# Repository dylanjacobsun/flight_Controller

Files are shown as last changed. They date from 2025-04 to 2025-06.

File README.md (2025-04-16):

# Objective
Purpose of this project is to develop an autonomous flying wing that will fly waypoint
missions. I am designing and building everything myself including electrical schematics,
PCB layout, component assembly, and system testing. The flight controller will be running 
on FreeRTOS and will be programmed in C.

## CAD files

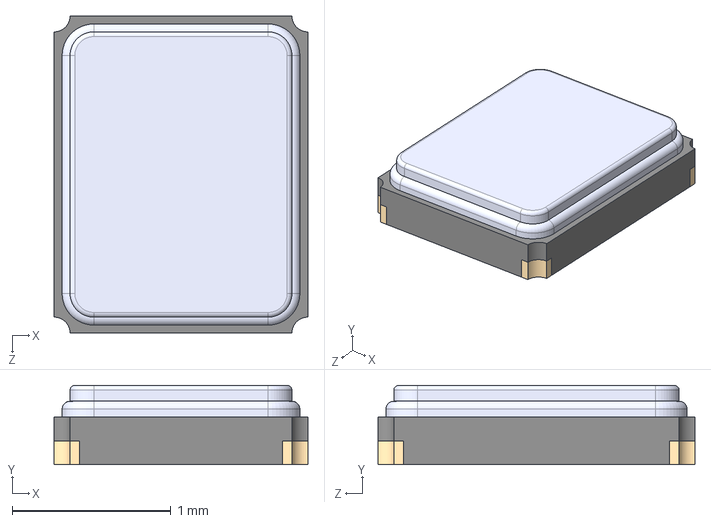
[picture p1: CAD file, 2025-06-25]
Components/Tranny_OSC.step
1.60 x 0.5 x 2.00 mm

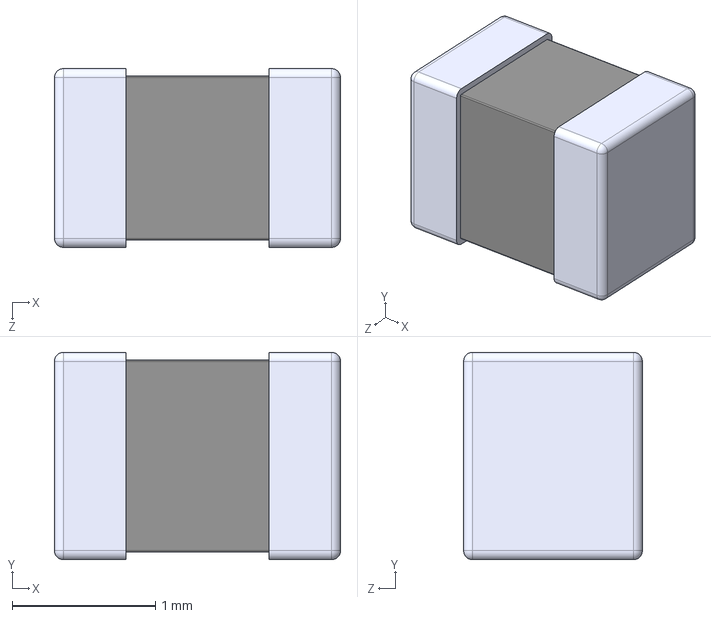
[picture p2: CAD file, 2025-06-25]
Components/15uH_Inductor.step
2.00 x 1.45 x 1.25 mm

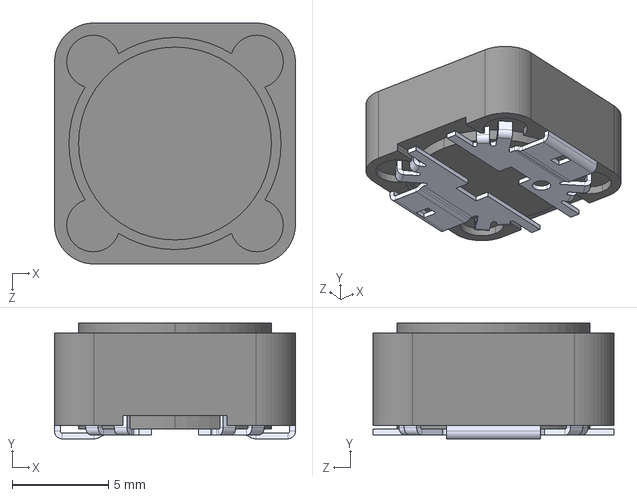
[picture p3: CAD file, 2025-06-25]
Components/4.7uH_7.18A.step
12.5 x 6.00 x 12.5 mm

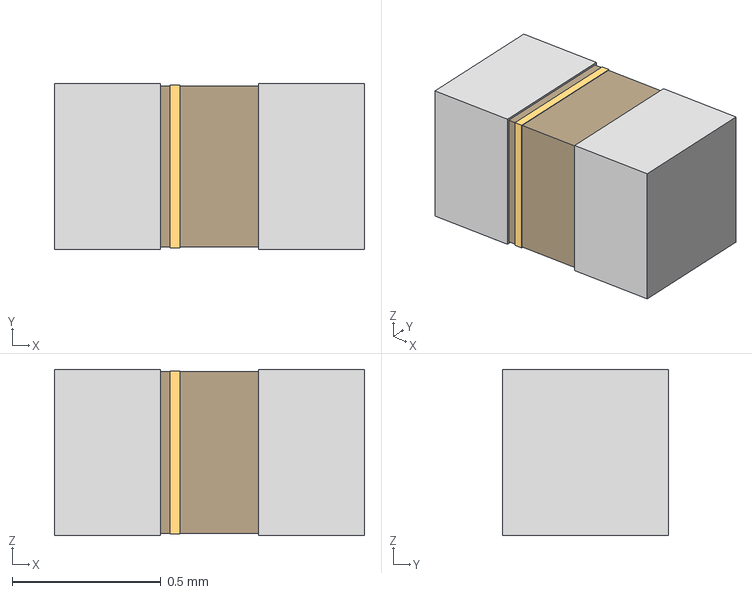
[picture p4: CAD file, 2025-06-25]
Components/10nH_Inductor.step
1.04 x 0.558 x 0.559 mm

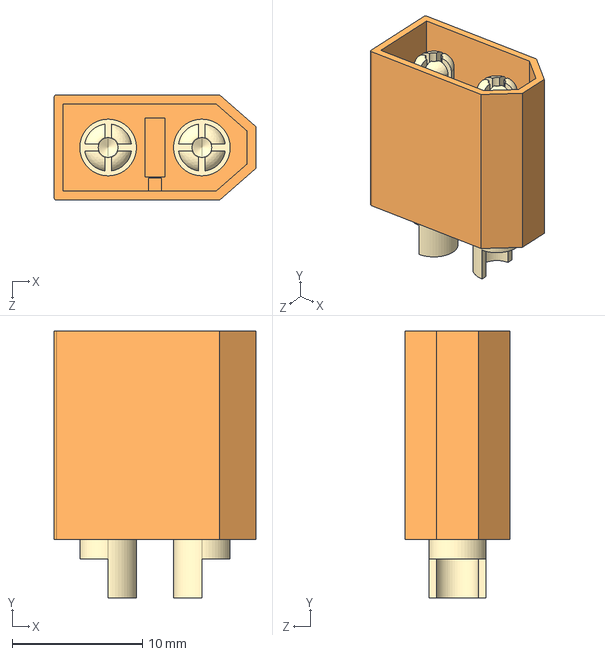
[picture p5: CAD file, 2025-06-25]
Components/XT60-M.step
15.5 x 20.5 x 8.10 mm

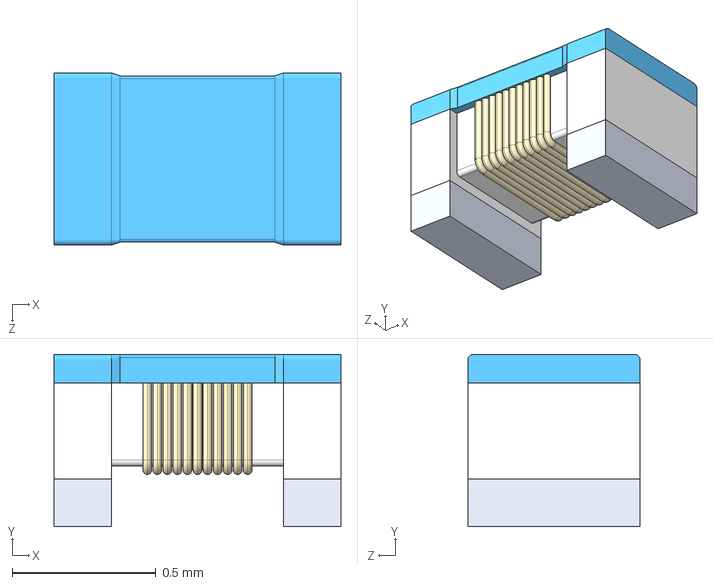
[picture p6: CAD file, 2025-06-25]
Components/3.0nH_Inductor.step
1.00 x 0.6 x 0.6 mm

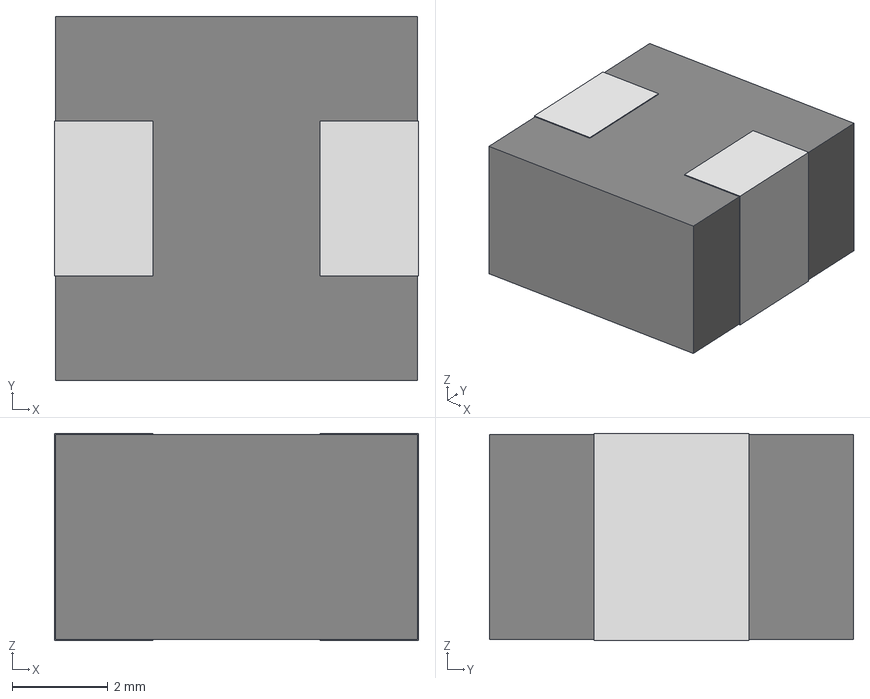
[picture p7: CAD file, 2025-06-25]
Components/3.3uH_3.94A.step
7.62 x 7.62 x 4.34 mm

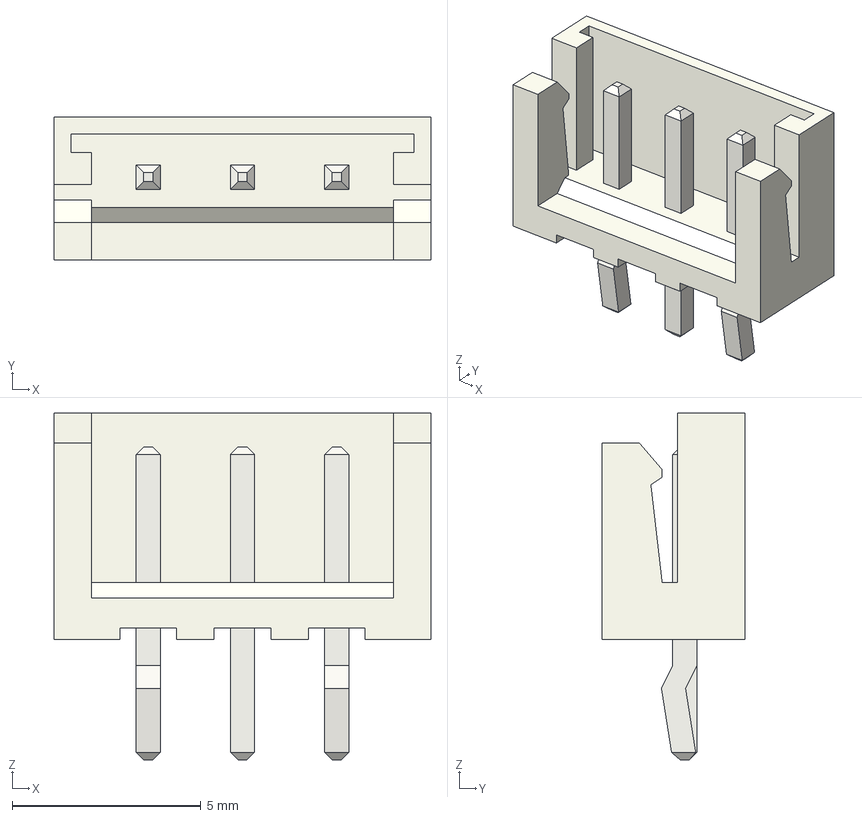
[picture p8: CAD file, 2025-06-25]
Components/JST_EH_B3B-EH-A_1x03_P2.50mm_Vertical.step
10.0 x 3.80 x 9.20 mm

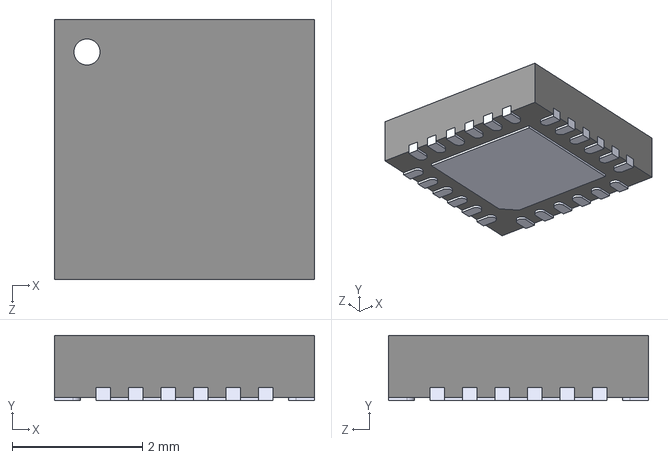
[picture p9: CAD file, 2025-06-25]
Components/Tranny.step
4.00 x 1.00 x 4.00 mm

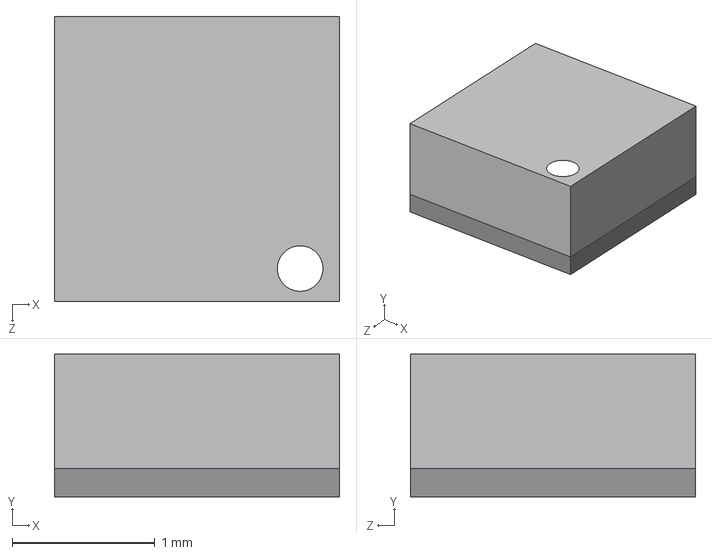
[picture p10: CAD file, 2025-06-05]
Components/Magnetometer.STEP
2.00 x 1.00 x 2.00 mm

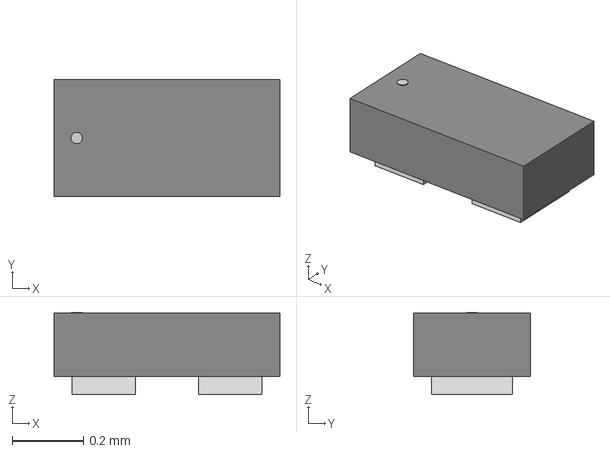
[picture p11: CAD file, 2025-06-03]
Components/ESD_6V.step
0.636 x 0.33 x 0.231 mm

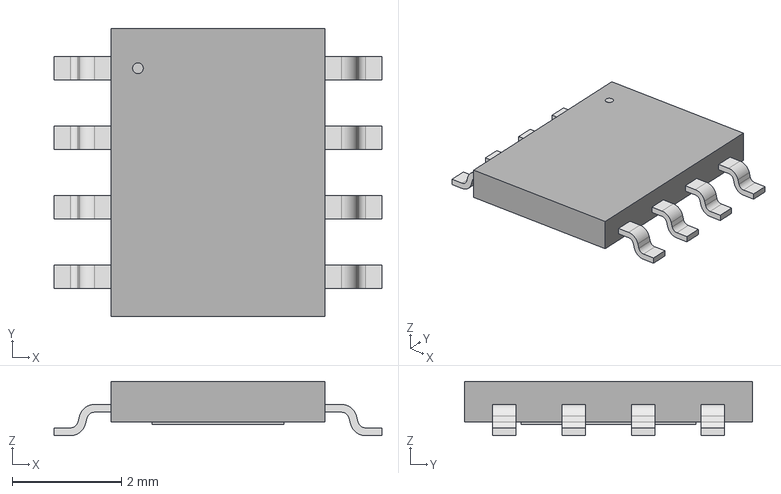
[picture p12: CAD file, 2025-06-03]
Components/3.3V-LDO (1).step
5.99 x 5.26 x 0.993 mm

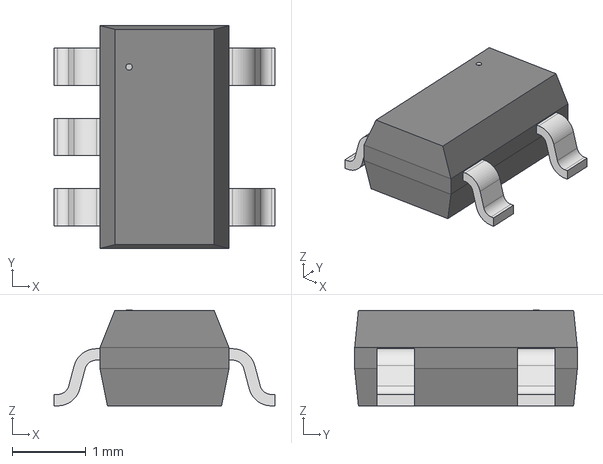
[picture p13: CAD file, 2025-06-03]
Components/Current-Limiter-500mA (1).step
3.00 x 3.02 x 1.30 mm

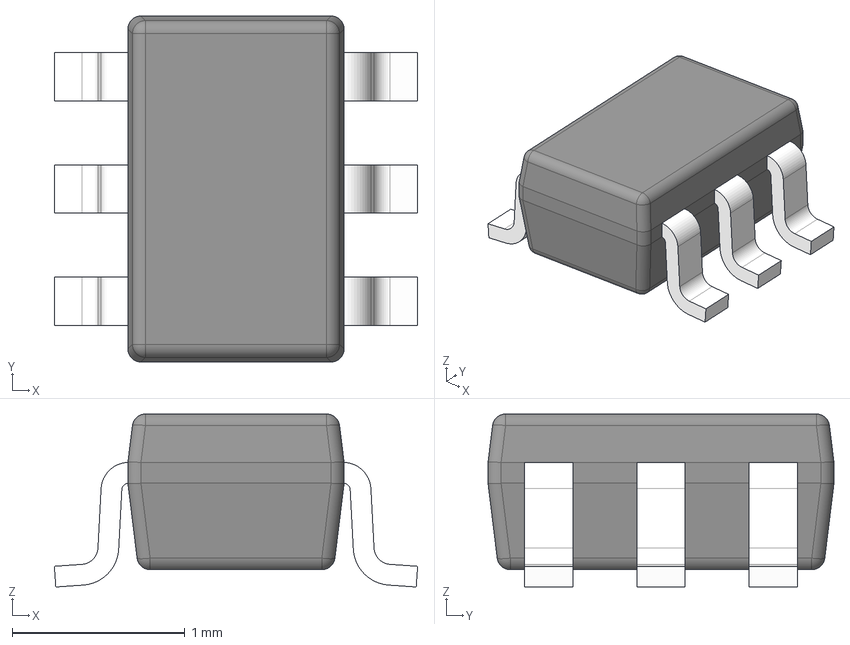
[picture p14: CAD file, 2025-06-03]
Components/Ideal_diode (1).stp
2.10 x 2.00 x 1.00 mm
BODY-SOT
LEAD-SOT x 6
PIN1-ID

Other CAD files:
Components/10nF_Cap_0603.step
Components/2.2uF_CAP_0603.step
Components/01uF_Cap_0603.step
Components/33.2Resistor.step
Components/0.22Cap.step
Components/01uF_CAP.step
Components/10kResistor.step
Components/10uF_cap.step
Components/22Uf_CAP.step
Components/3.3Buck.step
Components/3_3_Inductor.step
Components/Crystal.step
Components/DPS368XTSA1.step
Components/ICM-42670-P.step
Components/STM32F446VET6.step
Components/TESEO-LIV3F.step
Components/TPS22944 (1).stp
Components/U.FL-R-SMT_10_.step
Components/usbc.stp

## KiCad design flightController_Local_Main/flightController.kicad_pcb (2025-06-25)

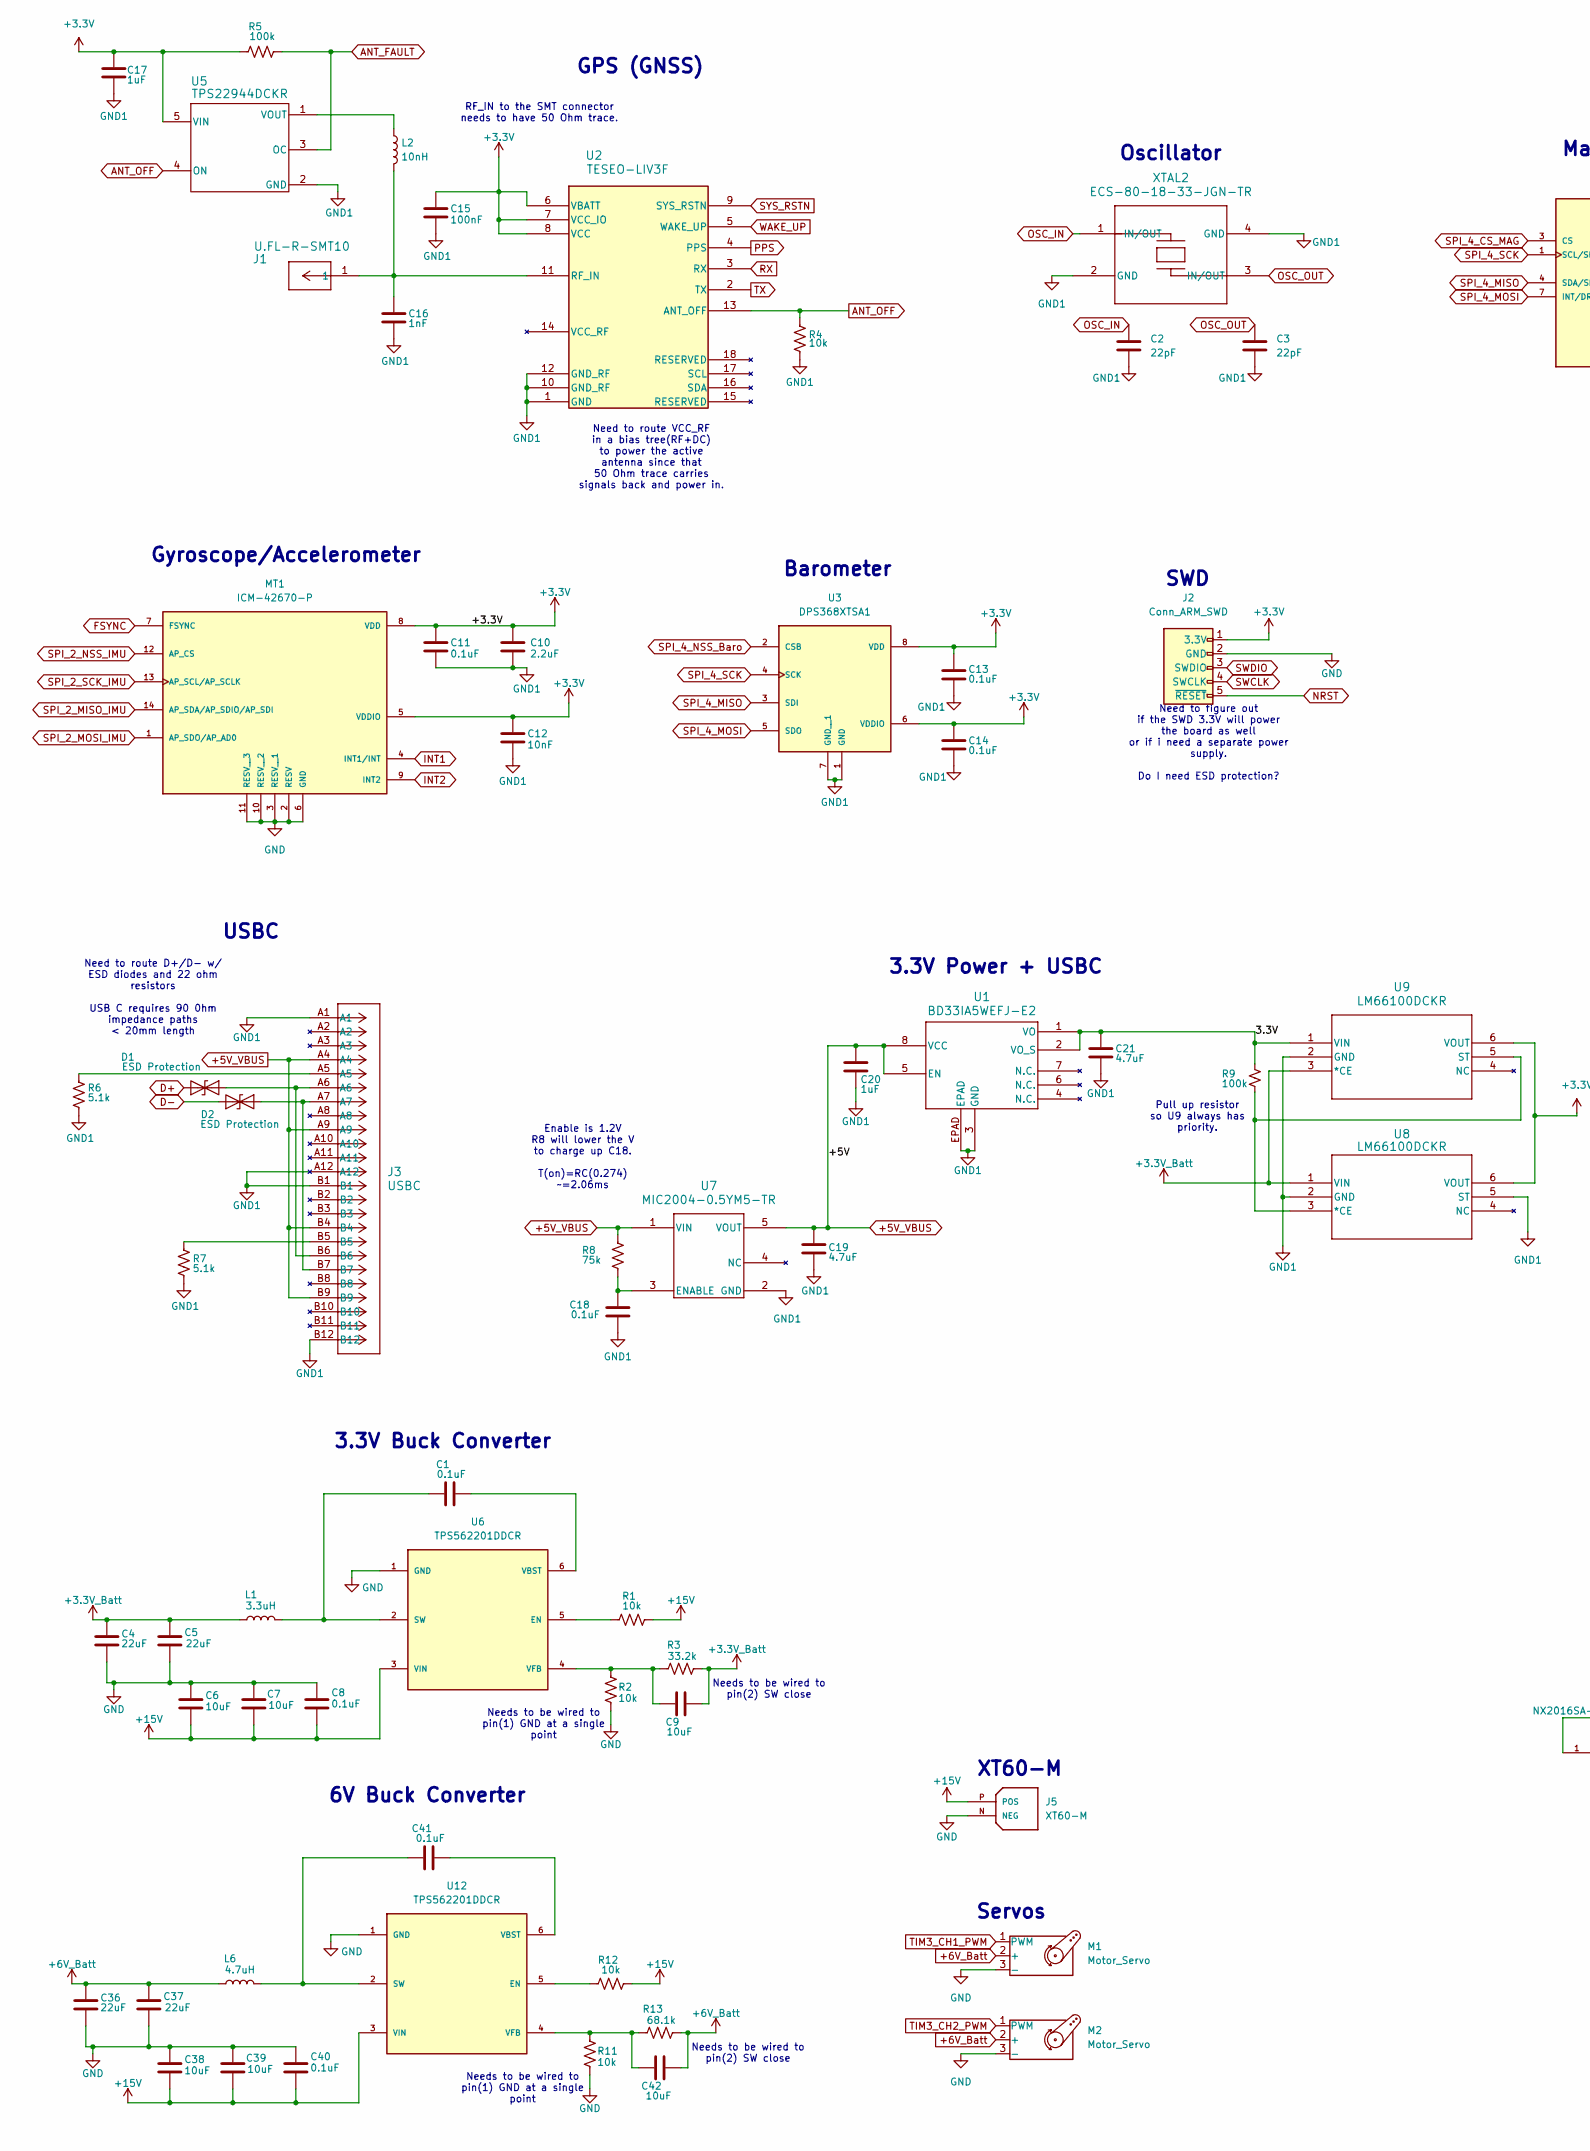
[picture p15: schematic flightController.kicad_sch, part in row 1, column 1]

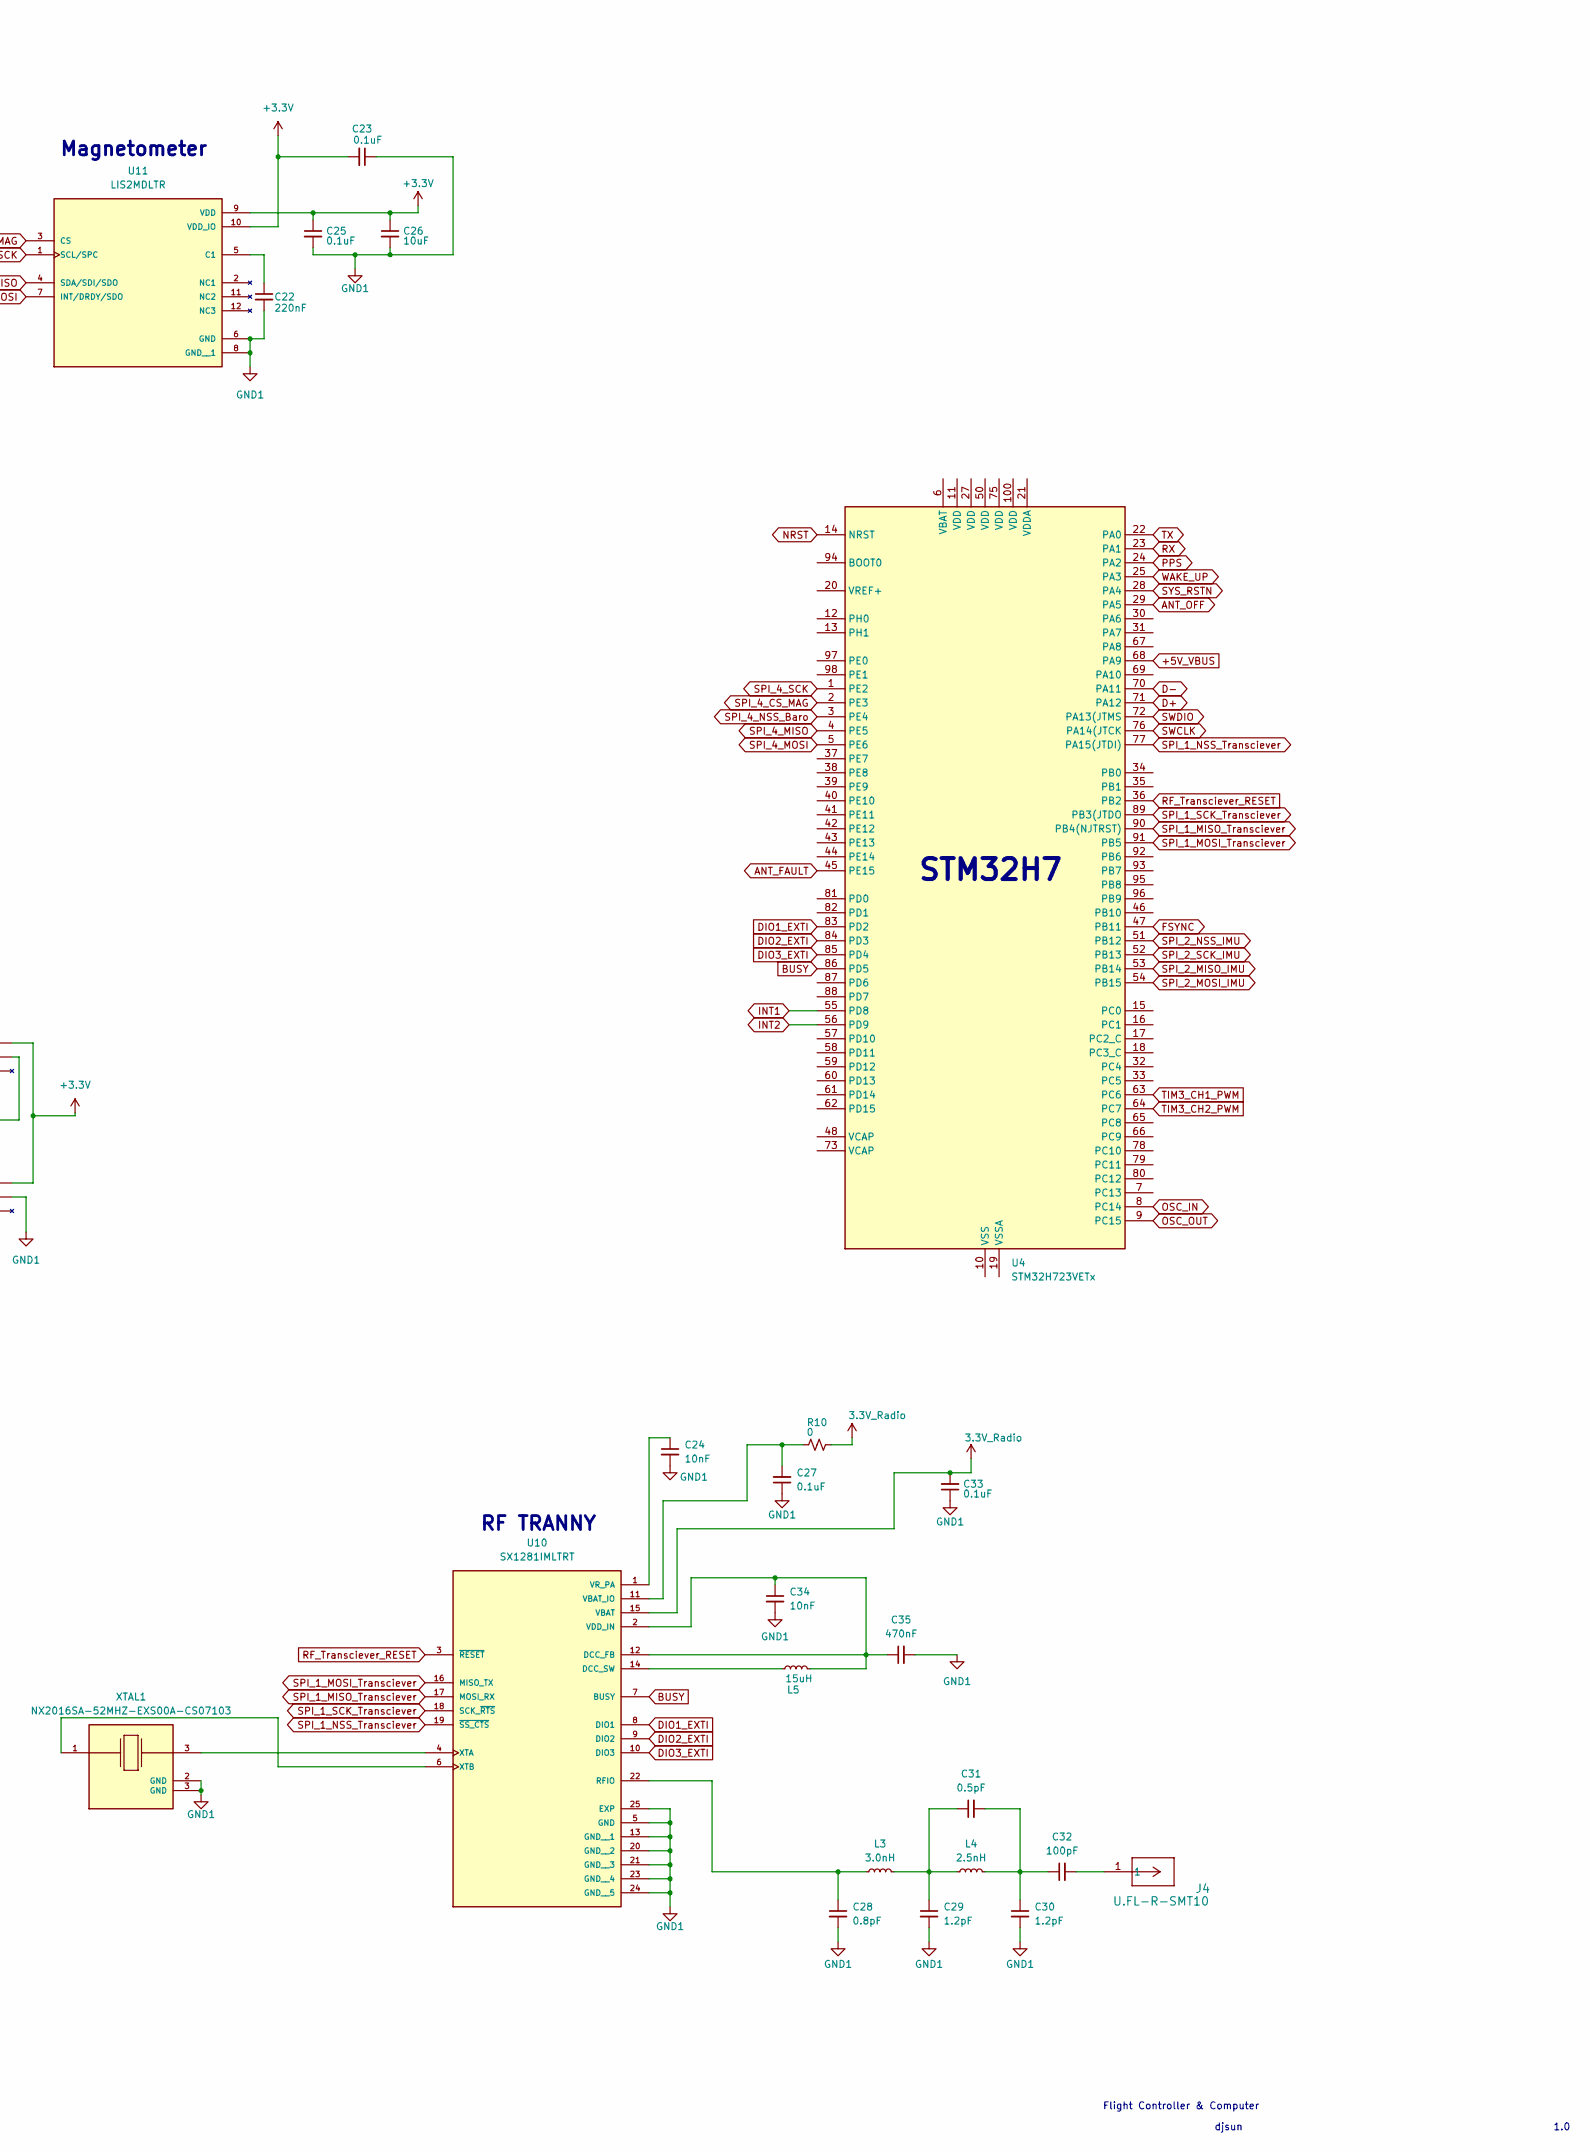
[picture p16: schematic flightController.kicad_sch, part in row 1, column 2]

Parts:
C1, C8, C11, C13, C14, C18, C23, C25, C27, C33, C40, C41: 0.1uF; C_0603_1608Metric
C2, C3: 22pF; C_0603_1608Metric
C4, C5, C36, C37: 22uF; C_0805_2012Metric
C6, C7, C26, C38, C39: 10uF; C_1206_3216Metric
C9, C42: 10uF; C_0805_2012Metric
C10: 2.2uF; C_0603_1608Metric
C12, C24, C34: 10nF; C_0603_1608Metric
C15: 100nF; C_0603_1608Metric
C16: 1nF; C_0603_1608Metric
C17, C20: 1uF; C_0603_1608Metric
C19, C21: 4.7uF; C_0603_1608Metric
C22: 220nF; C_0603_1608Metric
C28: 0.8pF; C_0603_1608Metric
C29, C30: 1.2pF; C_0603_1608Metric
C31: 0.5pF; C_0603_1608Metric
C32: 100pF; C_0603_1608Metric
C35: 470nF; C_0603_1608Metric
D1, D2: ESD Protection; ESD_6V (3)
J1, J4: U.FL-R-SMT10; U.FL_CONN_v.UL
J2: Conn_ARM_SWD; PinHeader_1x05_P1.27mm_Vertical
J3: USBC; USB_C_Receptacle_Molex_105450-0101
J5: XT60-M; PARTREV V1.2
L1: 3.3uH; 3.3uH_3.94A
L2: 10nH; 10nH_Inductor
L3: 3.0nH; 3.0nH_Inductor
L4: 2.5nH; 3.0nH_Inductor
L5: 15uH; 15uH_Inductor
L6: 4.7uH; 4.7uH_7.18A
M1, M2: Motor_Servo; JST_XH_B3B-XH-AM_1x03_P2.50mm_Vertical
MT1: ICM-42670-P; XDCR_ICM-42670-P; PARTREV 1.1
R1, R2, R4, R11, R12: 10k; R_0603_1608Metric
R3: 33.2k; R_0603_1608Metric
R5, R9: 100k; R_0603_1608Metric
R6, R7: 5.1k; R_0603_1608Metric
R8: 75k; R_0603_1608Metric
R10: 0; R_0603_1608Metric
R13: 68.1k; R_0603_1608Metric
U1: BD33IA5WEFJ-E2; 3.3V-LDO (2)
U2: TESEO-LIV3F
U3: DPS368XTSA1; XDCR_DPS368XTSA1
U4: STM32H723VETx; LQFP-100_14x14mm_P0.5mm
U5: TPS22944DCKR; TPS22944 (2)
U6, U12: TPS562201DDCR; 3.3Buck; PARTREV A
U7: MIC2004-0.5YM5-TR; Current-Limiter-500mA (1)
U8, U9: LM66100DCKR; Ideal_diode (2)
U10: SX1281IMLTRT; XCVR_SX1281IMLTRT; PARTREV 3.3
U11: LIS2MDLTR; Magnetometer; PARTREV Rev 5
XTAL1: NX2016SA-52MHZ-EXS00A-CS07103; Tranny_OSC; PARTREV N/A
XTAL2: ECS-80-18-33-JGN-TR; Crystal

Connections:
3.3V_Radio: C33.2, R10.1, U10.15 (VBAT)
+3.3V: C10.1, C11.1, C12.1, C13.1, C14.1, C15.1, C17.1, C23.2, C25.1, C26.1, J2.1 (3.3V), MT1.5 (VDDIO), MT1.8 (VDD), R5.2, U2.6 (VBATT), U2.7 (VCC_IO), U2.8 (VCC), U3.6 (VDDIO), U3.8 (VDD), U5.5 (VIN), U8.6 (VOUT), U9.6 (VOUT), U11.9 (VDD), U11.10 (VDD_IO)
+3.3V_Batt: C4.1, C5.1, C9.2, L1.1, R3.1, U8.1 (VIN), U9.3 (*CE)
+5V_VBUS: C19.1, C20.1, J3.A4, J3.A9, J3.B4, J3.B9, R8.1, U1.5 (EN), U1.8 (VCC), U4.68 (PA9), U7.1 (VIN), U7.5 (VOUT)
+6V_Batt: C36.1, C37.1, C42.2, L6.1, M1.2 (+), M2.2 (+), R13.1
+15V: C6.2, C7.2, C8.2, C38.2, C39.2, C40.2, J5.P (POS), R1.2, R12.2, U6.3 (VIN), U12.3 (VIN)
/3.3V: C21.1, R9.1, U1.1 (VO), U1.2 (VO_S), U9.1 (VIN)
ANT_FAULT: R5.1, U4.45 (PE15), U5.3 (OC)
ANT_OFF: R4.1, U2.13 (ANT_OFF), U4.29 (PA5), U5.4 (ON)
BUSY: U4.86 (PD5), U10.7 (BUSY)
D+: D1.1 (A1), U4.71 (PA12)
D-: D2.1 (A1), U4.70 (PA11)
DIO1_EXTI: U4.83 (PD2), U10.8 (DIO1)
DIO2_EXTI: U4.84 (PD3), U10.9 (DIO2)
DIO3_EXTI: U4.85 (PD4), U10.10 (DIO3)
FSYNC: MT1.7 (FSYNC), U4.47 (PB11)
GND: C4.2, C5.2, C6.1, C7.1, C8.1, C36.2, C37.2, C38.1, C39.1, C40.1, J2.2 (GND), J5.N (NEG), M1.3 (-), M2.3 (-), MT1.2 (RESV), MT1.3 (RESV__1), MT1.6 (GND), MT1.10 (RESV__2), MT1.11 (RESV__3), R2.1, R11.1, U6.1 (GND), U12.1 (GND)
INT1: MT1.4 (INT1/INT), U4.55 (PD8)
INT2: MT1.9 (INT2), U4.56 (PD9)
NRST: J2.5 (~RESET), U4.14 (NRST)
unnamed: C29.1, C31.1, L3.2, L4.1
unnamed: C30.1, C31.2, C32.1, L4.2
unnamed: C32.2, J4.1
unnamed: D1.2 (A2), J3.A6, J3.B6
unnamed: D2.2 (A2), J3.A7, J3.B7
unnamed: J3.A5, R6.1
unnamed: J3.B5, R7.1
unnamed: C16.1, J1.1, L2.2, U2.11 (RF_IN)
unnamed: U4.10 (VSS), U4.26 (VSS), U4.49 (VSS), U4.74 (VSS), U4.99 (VSS)
unnamed: L2.1, U5.1 (VOUT)
unnamed: R1.1, U6.5 (EN)
unnamed: C1.1, L1.2, U6.2 (SW)
unnamed: C1.2, U6.6 (VBST)
unnamed: C9.1, R2.2, R3.2, U6.4 (VFB)
unnamed: C18.1, R8.2, U7.3 (ENABLE)
unnamed: R9.2, U8.3 (*CE), U9.5 (ST)
unnamed: C34.1, C35.1, L5.2, U10.2 (VDD_IN), U10.12 (DCC_FB)
unnamed: L5.1, U10.14 (DCC_SW)
unnamed: C28.1, L3.1, U10.22 (RFIO)
unnamed: C27.2, R10.2, U10.11 (VBAT_IO)
unnamed: C24.1, U10.1 (VR_PA)
unnamed: U10.6 (XTB), XTAL1.1
unnamed: C22.1, U11.5 (C1)
unnamed: R12.1, U12.5 (EN)
unnamed: C41.1, L6.2, U12.2 (SW)
unnamed: C41.2, U12.6 (VBST)
unnamed: C42.1, R11.2, R13.2, U12.4 (VFB)
OSC_IN: C2.2, U4.8 (PC14), XTAL2.1 (IN/OUT)
OSC_OUT: C3.2, U4.9 (PC15), XTAL2.3 (IN/OUT)
PPS: U2.4 (PPS), U4.24 (PA2)
RF_Transciever_RESET: U4.36 (PB2), U10.3 (~RESET)
RX: U2.3 (RX), U4.23 (PA1)
SPI_1_MISO_Transciever: U4.90 (PB4(NJTRST)), U10.17 (MOSI_RX)
SPI_1_MOSI_Transciever: U4.91 (PB5), U10.16 (MISO_TX)
SPI_1_NSS_Transciever: U4.77 (PA15(JTDI)), U10.19 (~SS_CTS)
SPI_1_SCK_Transciever: U4.89 (PB3(JTDO), U10.18 (SCK_~RTS)
SPI_2_MISO_IMU: MT1.14 (AP_SDA/AP_SDIO/AP_SDI), U4.53 (PB14)
SPI_2_MOSI_IMU: MT1.1 (AP_SDO/AP_AD0), U4.54 (PB15)
SPI_2_NSS_IMU: MT1.12 (AP_CS), U4.51 (PB12)
SPI_2_SCK_IMU: MT1.13 (AP_SCL/AP_SCLK), U4.52 (PB13)
SPI_4_CS_MAG: U4.2 (PE3), U11.3 (CS)
SPI_4_MISO: U3.3 (SDI), U4.4 (PE5), U11.4 (SDA/SDI/SDO)
SPI_4_MOSI: U3.5 (SDO), U4.5 (PE6), U11.7 (INT/DRDY/SDO)
SPI_4_NSS_Baro: U3.2 (CSB), U4.3 (PE4)
SPI_4_SCK: U3.4 (SCK), U4.1 (PE2), U11.1 (SCL/SPC)
SWCLK: J2.4 (SWCLK), U4.76 (PA14(JTCK)
SWDIO: J2.3 (SWDIO), U4.72 (PA13(JTMS)
SYS_RSTN: U2.9 (SYS_RSTN), U4.28 (PA4)
TIM3_CH1_PWM: M1.1 (PWM), U4.63 (PC6)
TIM3_CH2_PWM: M2.1 (PWM), U4.64 (PC7)
TX: U2.2 (TX), U4.22 (PA0)
WAKE_UP: U2.5 (WAKE_UP), U4.25 (PA3)

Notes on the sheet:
Gyroscope/Accelerometer
6V Buck Converter
Pull up resistor so U9 always has priority.
STM32H7
Flight Controller & Computer
Magnetometer
Need to route D+/D- w/ ESD diodes and 22 ohm resistors USB C requires 90 0hm impedance paths < 20mm length
1.0
Needs to be wired to pin(1) GND at a single point
Need to figure out if the SWD 3.3V will power the board as well or if i need a separate power supply. Do I need ESD protection?
djsun
Needs to be wired to pin(2) SW close
3.3V Buck Converter
XT60-M
Servos
USBC
GPS (GNSS)
RF TRANNY
Barometer
RF_IN to the SMT connector needs to have 50 Ohm trace.
Need to route VCC_RF in a bias tree(RF+DC) to power the active antenna since that 50 Ohm trace carries signals back and power in.
Enable is 1.2V R8 will lower the V to charge up C18. T(on)=RC(0.274) ~=2.06ms
SWD
Oscillator
3.3V Power + USBC

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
Board: 2 copper layers, 85 parts (0 on the bottom side), 73 nets, no tracks yet.

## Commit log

2025-04-16 Adding Initial Folders for flight controller schematic
    [0.22Cap.step, 3.3Buck.step, Crystal.step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]
2025-04-16 Changing Componenets_local_main to Components
    [0.22Cap.step, 3.3Buck.step, Crystal.step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]
2025-04-17 adding footprints and models for buck
    [01uF_CAP.step, 10kResistor.step, 10uF_cap.step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]
2025-04-18 Adding caps to IMU and Barometer
    [01uF_Cap_0603.step, 10nF_Cap_0603.step, 2.2uF_CAP_0603.step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]
2025-04-24 Making changes to GPS
    [flightController.kicad_sch]
2025-05-02 Adding GPS passives and SWD
    [TPS22944 (1).stp, flightController.kicad_sch]
2025-06-03 Adding updates
    [3.3V-LDO (1).step, Current-Limiter-500mA (1).step, ESD_6V.step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]
2025-06-05 Adding the magnetometer and changing SPI pin outs
    [Magnetometer.STEP, flightController.kicad_sch]
2025-06-25 Adding all step files and footprints
    [10nH_Inductor.step, 15uH_Inductor.step, 3.0nH_Inductor.step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]

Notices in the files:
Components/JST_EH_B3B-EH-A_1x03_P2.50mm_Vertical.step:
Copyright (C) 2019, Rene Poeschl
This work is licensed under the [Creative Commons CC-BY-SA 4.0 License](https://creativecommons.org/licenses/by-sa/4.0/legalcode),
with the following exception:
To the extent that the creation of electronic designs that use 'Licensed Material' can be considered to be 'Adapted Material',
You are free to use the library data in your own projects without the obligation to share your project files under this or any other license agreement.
